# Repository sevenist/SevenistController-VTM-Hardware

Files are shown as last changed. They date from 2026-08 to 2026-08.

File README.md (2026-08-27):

# Sevenist Controller — Hardware (VTM)

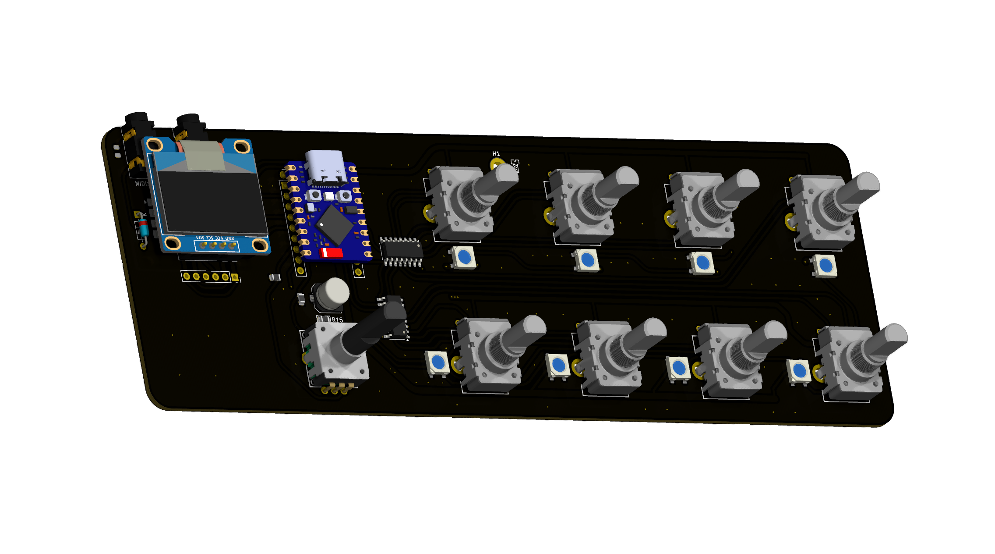
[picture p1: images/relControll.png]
PCB render


Custom PCB for the **Sevenist Controller**, a 64-track MIDI CC control surface built around an [ESP32-S3 Zero](https://docs.waveshare.com/ESP32-S3-Zero).

This repository holds the KiCad project, schematics and fabrication files for the board. The code for it : [VTM Firmware repository](https://github.com/sevenist/SevenistController-VTM-Firmware).

> **Status: updated, should work but not tested yet. will upload soon some BOM file.**
> Fabricate at your own risk until it's confirmed working.

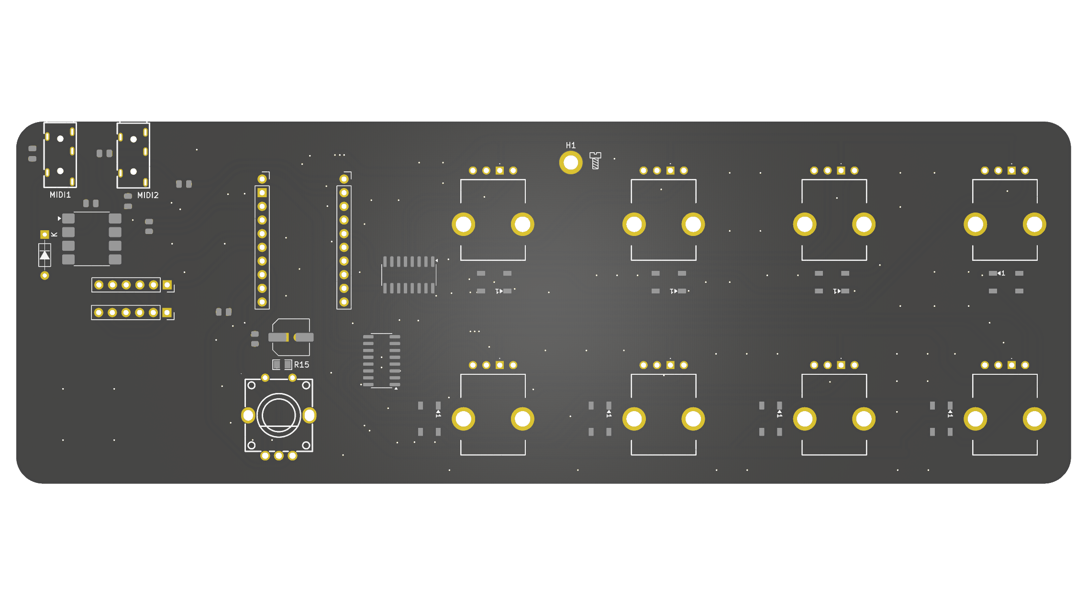
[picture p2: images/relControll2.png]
Assembly render

## Repository layout

```
relControll.kicad_pro / .kicad_sch / .kicad_pcb   KiCad 10 project, schematic, board
images/                                            Board renders
```

## License

Released under the [GPL-3.0](LICENSE) license.

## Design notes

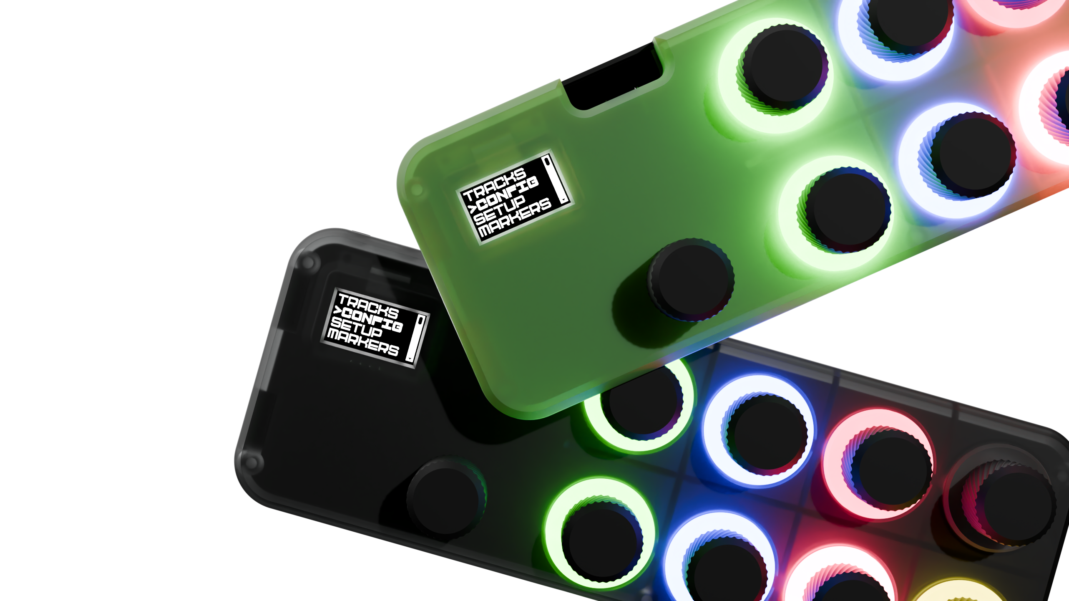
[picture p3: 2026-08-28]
images/Sevenist VTM Wallpaper.png

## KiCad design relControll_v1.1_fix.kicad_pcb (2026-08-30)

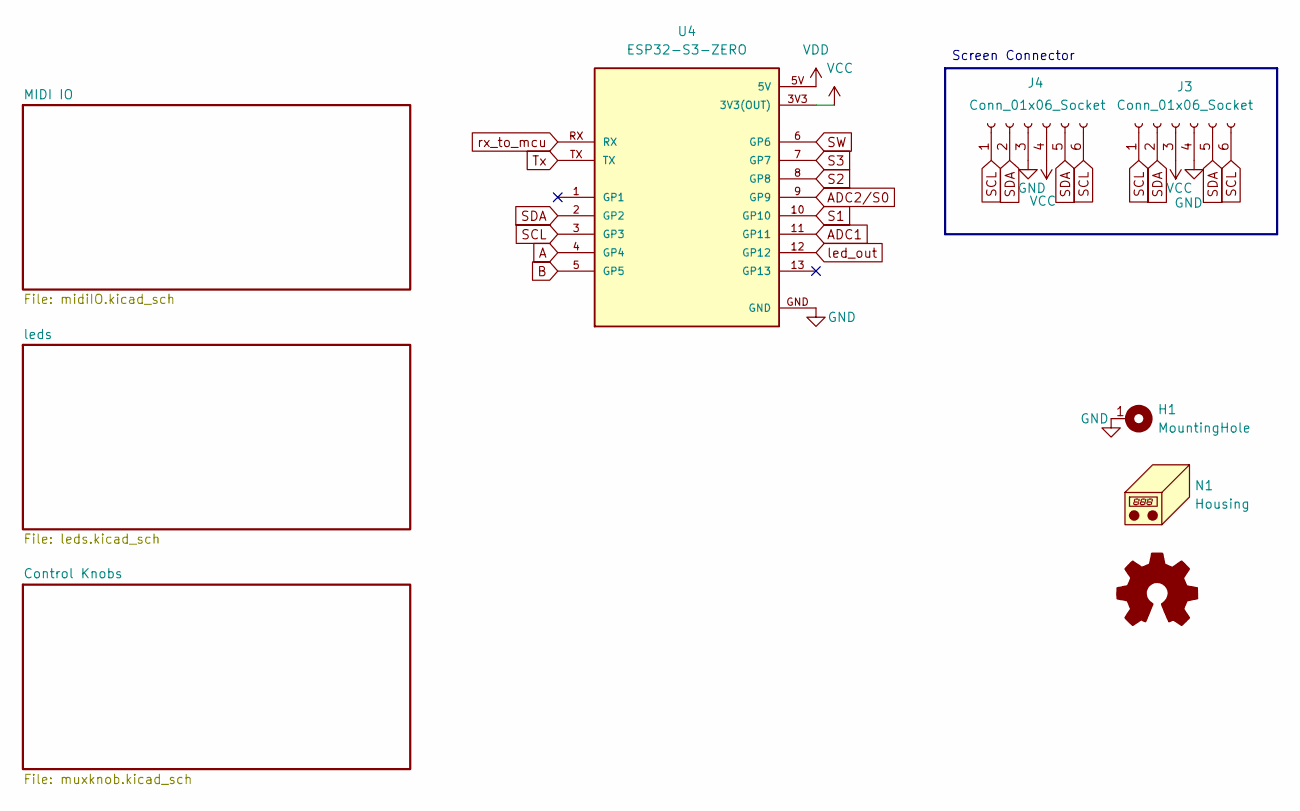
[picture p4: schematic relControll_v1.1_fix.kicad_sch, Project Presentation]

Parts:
H1: MountingHole; MountingHole_2.7mm_M2.5_ISO14580_Pad
J3, J4: Conn_01x06_Socket; PinSocket_1x06_P2.54mm_Vertical
N1: Housing; Screw_Generic_2.0x3.0mm_SilkScreen
U4: ESP32-S3-ZERO; MODULE_ESP32-S3-ZERO; PARTREV NA

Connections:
A: U4.4 (GP4); also elsewhere on the board
ADC1: U4.11 (GP11); also elsewhere on the board
ADC2/S0: U4.9 (GP9); also elsewhere on the board
B: U4.5 (GP5); also elsewhere on the board
GND: H1.1, J3.4, J4.3, U4.GND; also elsewhere on the board
S1: U4.10 (GP10); also elsewhere on the board
S2: U4.8 (GP8); also elsewhere on the board
S3: U4.7 (GP7); also elsewhere on the board
SCL: J3.1, J3.6, J4.1, J4.6, U4.3 (GP3)
SDA: J3.2, J3.5, J4.2, J4.5, U4.2 (GP2)
SW: U4.6 (GP6); also elsewhere on the board
Tx: U4.TX; also elsewhere on the board
VCC: J3.3, J4.4, U4.3V3 (3V3(OUT)); also elsewhere on the board
VDD: U4.5V; also elsewhere on the board
led_out: U4.12 (GP12); also elsewhere on the board
rx_to_mcu: U4.RX; also elsewhere on the board

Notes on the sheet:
Screen Connector

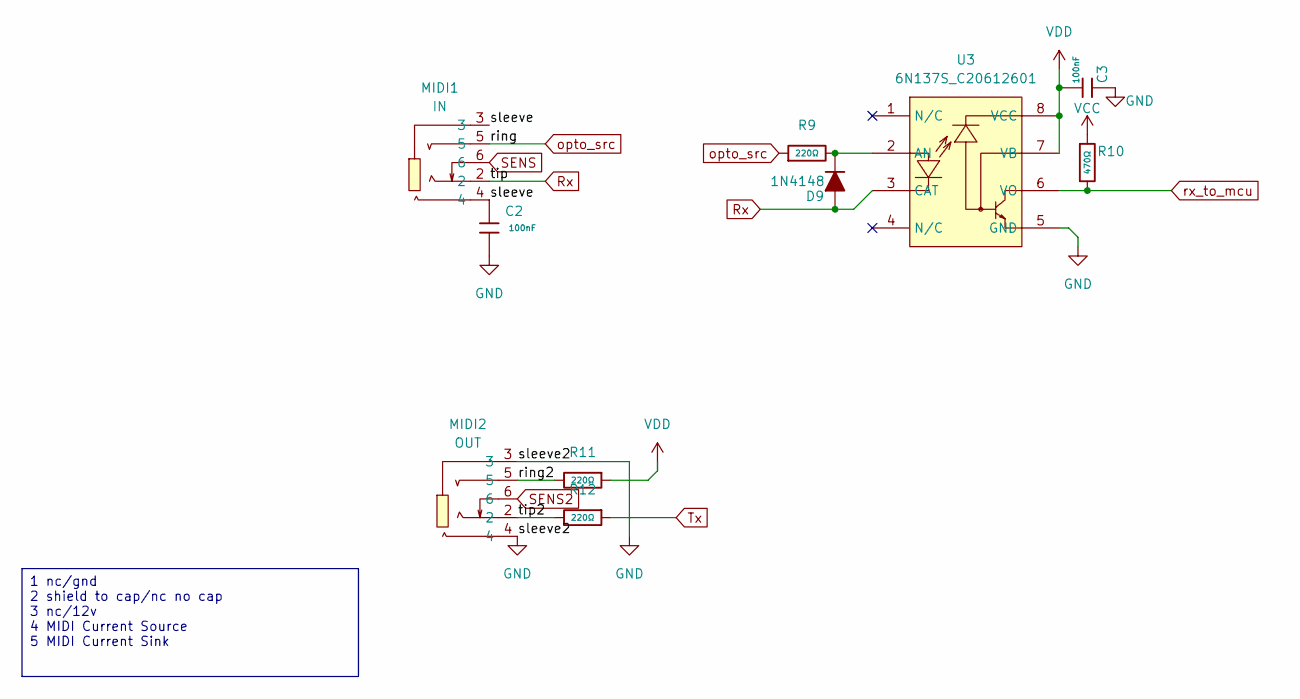
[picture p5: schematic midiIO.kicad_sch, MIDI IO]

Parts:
C2, C3: 100nF; C_0805; Voltage Rated 50V; Tolerance ±10%; Part CC0805KRX7R9BB104; LCSC C49678
D9: 1N4148; D_SOD123_axial
MIDI1: IN; AUDIO-TH_PJ-3270; MPN PJ-3270; LCSC Part C381134
MIDI2: OUT; AUDIO-TH_PJ-3270; MPN PJ-3270; LCSC Part C381134
R9, R11, R12: 220Ω; R_0805; Overload Voltage (Max) 150V; Tolerance ±1%; Part 0805W8F2200T5E; LCSC C17557
R10: 470Ω; R_0805; Overload Voltage (Max) 150V; Tolerance ±1%; Part 0805W8F4700T5E; LCSC C17710
U3: 6N137S_C20612601; SOP-8_6.605x9.655mm_P2.54mm; MPN 6N137S; LCSC Part C20612601

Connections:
/MIDI IO/ring2: MIDI2.5, R11.2
/MIDI IO/sleeve: C2.1, MIDI1.3, MIDI1.4
/MIDI IO/tip2: MIDI2.2, R12.2
GND: C2.2, C3.2, MIDI2.3, MIDI2.4, U3.5 (GND); also elsewhere on the board
unnamed: D9.1 (K), R9.2, U3.2 (AN)
Rx: D9.2 (A), MIDI1.2, U3.3 (CAT)
SENS: MIDI1.6
SENS2: MIDI2.6
Tx: R12.1; also elsewhere on the board
VCC: R10.1; also elsewhere on the board
VDD: C3.1, R11.1, U3.7 (VB), U3.8 (VCC); also elsewhere on the board
opto_src: MIDI1.5, R9.1
rx_to_mcu: R10.2, U3.6 (VO); also elsewhere on the board

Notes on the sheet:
1 nc/gnd 2 shield to cap/nc no cap 3 nc/12v 4 MIDI Current Source 5 MIDI Current Sink

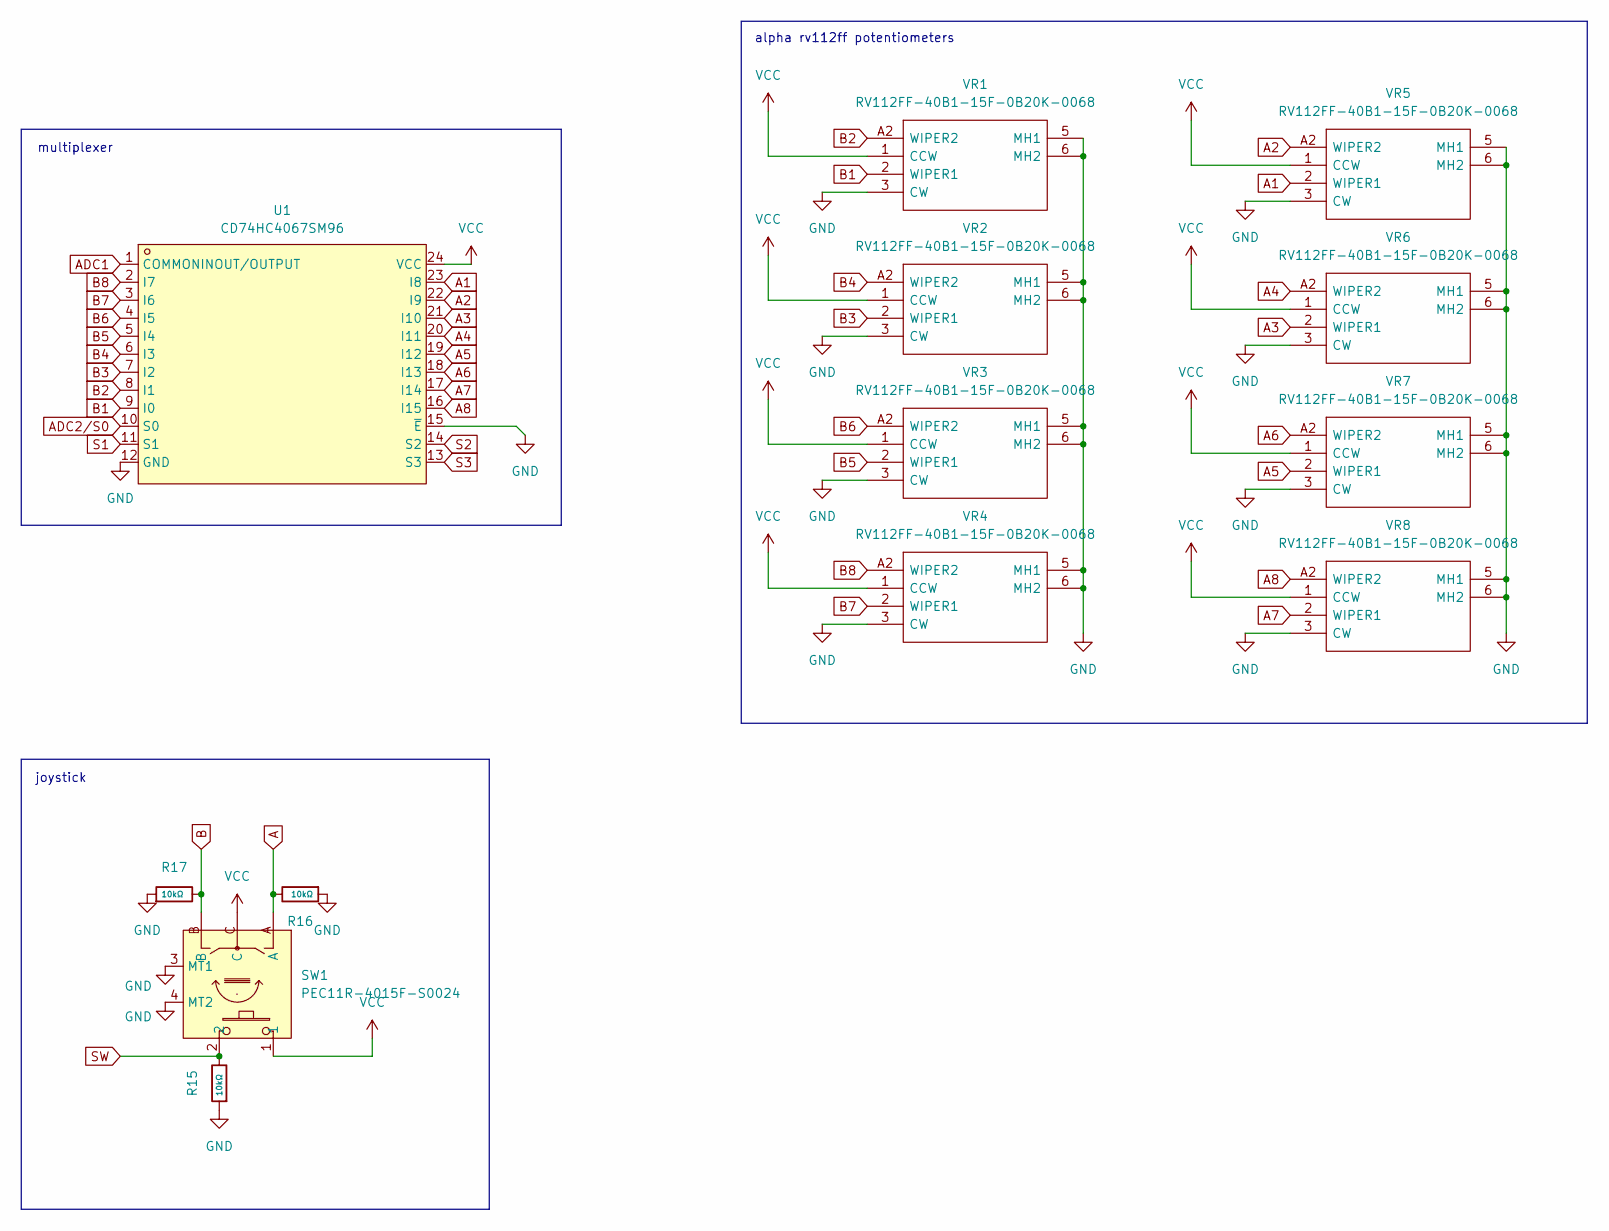
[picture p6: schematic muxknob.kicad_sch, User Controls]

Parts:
R15: 10kΩ; R0805; Overload Voltage (Max) 150V; Tolerance ±1%; Part 0805W8F1002T5E; LCSC C17414
R16, R17: 10kΩ; R_0805; Overload Voltage (Max) 150V; Tolerance ±1%; Part 0805W8F1002T5E; LCSC C17414
SW1: PEC11R-4015F-S0024; SW-TH_PEC12R-4130F-S0012; MPN PEC11R-4015F-S0024; LCSC Part C143789
U1: CD74HC4067SM96; SSOP-24_L8.1-W5.3-P0.65-LS7.8-BL; MPN CD74HC4067SM96; LCSC Part C98457
VR1, VR2, VR3, VR4, VR5, VR6, VR7, VR8: RV112FF-40B1-15F-0B20K-0068; RV112FF40B115F0B20K0068; Mouser Part Number 317-1240FF-15F-0B20K

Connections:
A: R16.2, SW1.A; also elsewhere on the board
A1: U1.23 (I8), VR5.2 (WIPER1)
A2: U1.22 (I9), VR5.A2 (WIPER2)
A3: U1.21 (I10), VR6.2 (WIPER1)
A4: U1.20 (I11), VR6.A2 (WIPER2)
A5: U1.19 (I12), VR7.2 (WIPER1)
A6: U1.18 (I13), VR7.A2 (WIPER2)
A7: U1.17 (I14), VR8.2 (WIPER1)
A8: U1.16 (I15), VR8.A2 (WIPER2)
ADC1: U1.1 (COMMONINOUT/OUTPUT); also elsewhere on the board
ADC2/S0: U1.10 (S0); also elsewhere on the board
B: R17.2, SW1.B; also elsewhere on the board
B1: U1.9 (I0), VR1.2 (WIPER1)
B2: U1.8 (I1), VR1.A2 (WIPER2)
B3: U1.7 (I2), VR2.2 (WIPER1)
B4: U1.6 (I3), VR2.A2 (WIPER2)
B5: U1.5 (I4), VR3.2 (WIPER1)
B6: U1.4 (I5), VR3.A2 (WIPER2)
B7: U1.3 (I6), VR4.2 (WIPER1)
B8: U1.2 (I7), VR4.A2 (WIPER2)
GND: R15.1, R16.1, R17.1, SW1.3 (MT1), SW1.4 (MT2), U1.12 (GND), U1.15 (~E), VR1.3 (CW), VR1.5 (MH1), VR1.6 (MH2), VR2.3 (CW), VR2.5 (MH1), VR2.6 (MH2), VR3.3 (CW), VR3.5 (MH1), VR3.6 (MH2), VR4.3 (CW), VR4.5 (MH1), VR4.6 (MH2), VR5.3 (CW), VR5.5 (MH1), VR5.6 (MH2), VR6.3 (CW), VR6.5 (MH1), VR6.6 (MH2), VR7.3 (CW), VR7.5 (MH1), VR7.6 (MH2), VR8.3 (CW), VR8.5 (MH1), VR8.6 (MH2); also elsewhere on the board
S1: U1.11 (S1); also elsewhere on the board
S2: U1.14 (S2); also elsewhere on the board
S3: U1.13 (S3); also elsewhere on the board
SW: R15.2, SW1.2; also elsewhere on the board
VCC: SW1.1, SW1.C, U1.24 (VCC), VR1.1 (CCW), VR2.1 (CCW), VR3.1 (CCW), VR4.1 (CCW), VR5.1 (CCW), VR6.1 (CCW), VR7.1 (CCW), VR8.1 (CCW); also elsewhere on the board

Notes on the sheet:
alpha rv112ff potentiometers
joystick
multiplexer

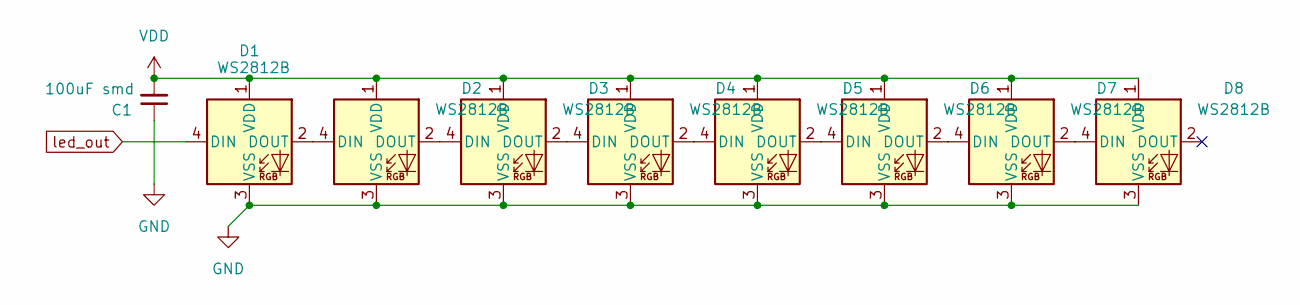
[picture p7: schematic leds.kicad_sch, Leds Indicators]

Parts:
C1: 100uF smd; C_Elec_6.3x5.4
D1, D2, D3, D4, D5, D6, D7, D8: WS2812B; LED_WS2812B_PLCC4_5.0x5.0mm_P3.2mm; LCSC C22461793

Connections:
GND: C1.1, D1.3 (VSS), D2.3 (VSS), D3.3 (VSS), D4.3 (VSS), D5.3 (VSS), D6.3 (VSS), D7.3 (VSS), D8.3 (VSS); also elsewhere on the board
unnamed: D1.2 (DOUT), D2.4 (DIN)
unnamed: D2.2 (DOUT), D3.4 (DIN)
unnamed: D3.2 (DOUT), D4.4 (DIN)
unnamed: D4.2 (DOUT), D5.4 (DIN)
unnamed: D5.2 (DOUT), D6.4 (DIN)
unnamed: D6.2 (DOUT), D7.4 (DIN)
unnamed: D7.2 (DOUT), D8.4 (DIN)
VDD: C1.2, D1.1 (VDD), D2.1 (VDD), D3.1 (VDD), D4.1 (VDD), D5.1 (VDD), D6.1 (VDD), D7.1 (VDD), D8.1 (VDD); also elsewhere on the board
led_out: D1.4 (DIN); also elsewhere on the board

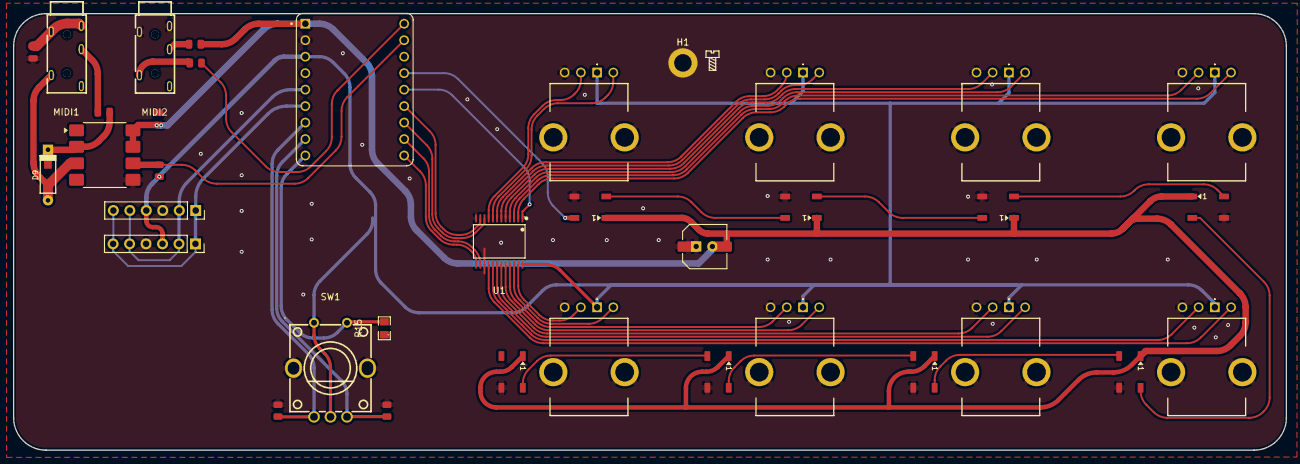
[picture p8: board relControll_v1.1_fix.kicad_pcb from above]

Board: 2 copper layers, 196.2 x 67.3 mm, 38 parts (1 on the bottom side), 45 nets.

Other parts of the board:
C1#2: 100uF; CP_Radial_D7.5mm_P2.50mm

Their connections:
GND: C1#2.1; also elsewhere on the board
VDD: C1#2.2; also elsewhere on the board

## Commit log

2026-08-28 wallpaper :)
    [relControll.kicad_sch]
2026-08-30 new pcb design
    changed footprint for esp32s3 zero devboard changed dual multiplexer to single 16ch multiplexer, changed some pins functions
    [leds.kicad_sch, midiIO.kicad_sch, muxknob.kicad_sch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]
